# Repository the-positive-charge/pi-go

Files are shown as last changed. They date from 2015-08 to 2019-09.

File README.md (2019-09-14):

# pi-go
Pi-Go Kickstarter - Design Files

## IMPORTANT NOTICE 2019-09-14
**This design requires modification to add the 5V "safety" protection and the ID EEPROM as
specified by the Raspberry Pi Hat specification: https://github.com/raspberrypi/hats**

This directory contains the Cadsoft Eagle (v7.3) design files: Schematic, Layout and related files
The "Gerber Files" directory contains the fabrication files
The "Other Files" directory contains the BOM and other related files (design rules, netlist, etc.)

The Pi-Go design is released under the TAPR Open Hardware License:
https://www.tapr.org/ohl.html

The documentation for the Pi-Go design is released under the Creative Commons
Attribution-ShareAlike v4.0 license:
http://creativecommons.org/licenses/by-sa/4.0/

See the respective license files:
LICENSE-design.txt for full TAPR OHL text
LICENSE-documents.txt for full CC-BY-SA v4.0 text

2015 CC-BY-SA The Positive Charge, LLC

The Positive Charge, LLC has been disolved. Please give attribution to me directly (N8SQT)
2019 CC-BY-SA N8SQT / Bob Recny

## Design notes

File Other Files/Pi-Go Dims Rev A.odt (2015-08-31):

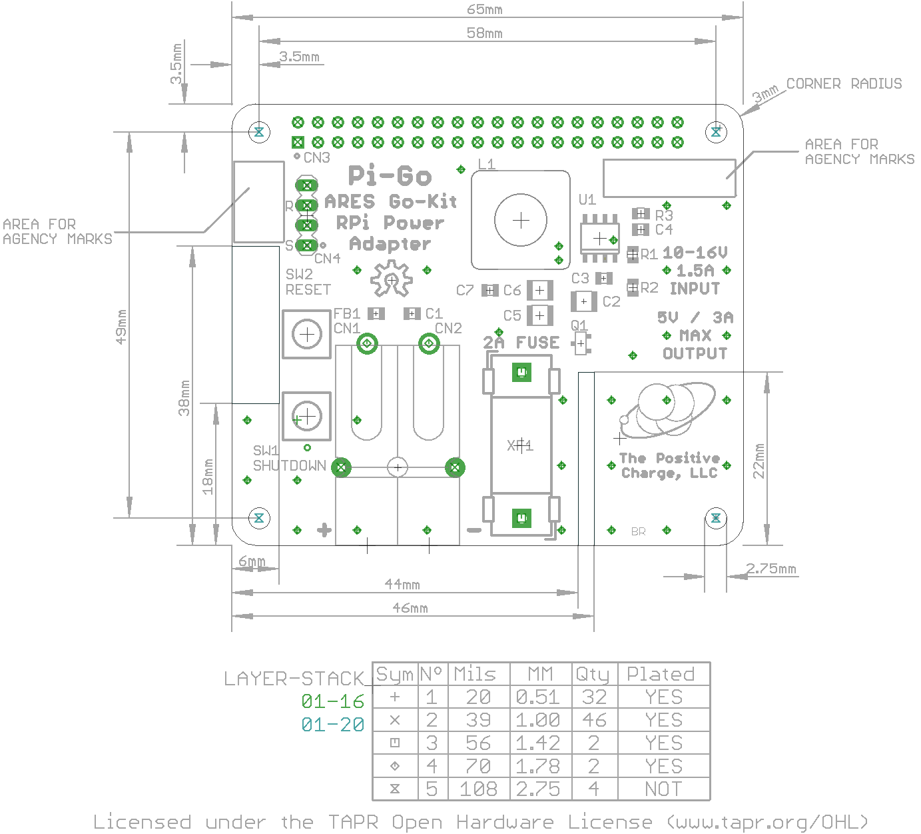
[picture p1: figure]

Board dimensions

- Dimensions in mm:
- Rounded corners = 3mm diameter, 4 places
- Milled slots
  - 20mm x 6mm on left edge
  - 2mm x 22mm on bottom edge

Notes:

- Board specifications for selected service level take precedence over these notes.
  - Material: FR-4
    - 1oz Copper External Layer
    - Thickness Tolerance ±0.0061”
  - Solder Mask: Standard Green, SMOBC
  - Vendor shall stamp agency marks on each board as required
  - Silkscreen Color = White, Component layer only
  - All holes size shall be located within 0.003” (0.08mm) diameter of true position from location shown on master pattern.
  - Finished hole size tolerance: ±003” (±0.08mm)
  - Front-to-Back layer registration to be within 0.003” (0.08mm)
  - Board outline shall conform to supplied Gerber data within 0.010” (0.25mm)
  - All internal corners 0.040” (1.01mm) of radius maximum

Board Stack-up – Use standard for service level, or:

All dimensions in inches unless otherwise noted:

Stack-up | Thickness | Tolerance (±) | Layer file ext. | Notes
Layer 1 | 0.0017 | 0.0004 | cmp | Top Layer
Laminate Core | 0.0580 | 0.0025
Layer 16 | 0.0017 | 0.0004 | sol | Bottom Layer
Overall | 0.0614 | 0.0061

The Positive Charge Pi-Go Rev A – 2015-08-11 Fabrication Details

Page 2 of 2 Hardware Design licensed under the TAPR Open Hardware License (www.tapr.org/OHL) (C) 2015 The Positive Charge, LLC, All text/Gerber and related documents licensed under the Creative Commons Attribution-ShareAlike 4.0 International License (http://creativecommons.org/licenses/by-sa/4.0/)

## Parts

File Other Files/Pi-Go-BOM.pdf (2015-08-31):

Pi-Go | Rev A | Page 1

Hardware Design licensed under the TAPR Open Hardware License (www.tapr.org/OHL)
(C) 2015 The Positive Charge, LLC, All text/Gerber and related documents licensed under the Creative Commons Attribution-ShareAlike 4.0 International License (http://creativecommons.org/licenses/by-sa/4.0/)
Qty Value | Parts | Description | MFG | MPN | DK-PN | NOTES | SMD | THD | Other (mech or DNI)
3 0.1uF | C1, C3, C7 | CAP CER 0.1UF 50V 10% X7R 0805 | Kemet | C0805C104K5RACTU | 399-1170-1-ND | 3
3 22uF | C2, C5, C6 | CAP CER 22UF 25V 10% X5R 1210 | Murata | GRM32ER61E226KE15L | 490-3889-1-ND | 3
1 1800pF | C4 | CAP CER 1800PF 50V 10% X7R 0805 | AVX Corporation | 08055C182KAT2A | 478-1374-1-ND | 1
2 1377G12 | CN1, CN2 | Anderson Powerpole 25A Pin Right Angle Bottom Low Force | Anderson Power | 1377G12 | 879-1377G12 (Mouser) | 2
1 SSW-120-01-T-D | CN3 | THROUGH-HOLE .025" SQ POST SOCKET | Sullins | SFH11-PBPC-D20-ST-BK | S9200-ND | Solder side mount | 1
1 DNI | CN4 | Pin Header – Holes Only, Do Not Install | N/A | N/A | N/A | Not Installed | | | 1
1 2A Fast Blow | F1 | FUSE GLASS 2A 250VAC 5X20MM | Bel Fuse Inc | 5MF 2-R | 507-1264-ND | Place in XF1 | | | 1
1 220R @ 100MHz, 3A | FB1 | FERRITE CHIP 220 OHM 3A 0805 | TDK Corporation | MPZ2012S221AT000 | 445-1568-1-ND | 1
1 10uH | L1 | FIXED IND 10UH 10A 16.5 MOHM SMD | Bourns | SRP1265A-100M | SRP1265A-100MCT-ND | 1
1 SI2343CDS | Q1 | MOSFET P-CH 30V 5.9A SOT-23 | Vishay Siliconix | SI2343CDS-T1-GE3 | SI2343CDS-T1-GE3CT-ND | 1
1 10K0 | R1 | RES SMD 10K OHM 1% 1/8W 0805 | Yageo | RC0805FR-0710KL | 311-10.0KCRCT-ND | 1
2 52K3 | R2, R3 | RES SMD 52.3K OHM 1% 1/8W 0805 | Yageo | RC0805FR-0752K3L | 311-52.3KCRCT-ND | 2
2 SWITCH-MOMENTARY-2SMD-4 | SW1, SW2 | SWITCH TACTILE SPST-NO 0.05A 24V | Apem | ADTSM61RVTR | 679-2381-1-ND | 2
1 AOZ1031A1 | U1 | IC REG BUCK ADJ 3A SYNC 8SOIC | Alpha & Omega | AOZ1031AI | 785-1253-1-ND | 1
1 1327 | XCN1 | Heavy Duty Power Connectors PP15/45 HOUSING ONLY RED | Anderson Power | 1327-BK | 879-1327-BK (Mouser) | Ass'y with CN1 | | | 1
1 1327BK | XCN2 | Heavy Duty Power Connectors PP15/45 HOUSING ONLY BLACK | Anderson Power | 1327G6-BK | 879-1327G6-BK (Mouser) | Ass'y with CN2 | | | 1
1 114555P2 | XCN3 | Anderson Powerpole Mounting Staple 2x1 | Anderson Power | 114555P2 | 879-114555P2 (Mouser) | 1
1 FUSE-5X20-HOLDER | XF1 | FUSE BLOK CARTRIDGE 300V 10A PCB | Littelfuse | 02540101Z | F1471-ND | 1
Parts Count | 16 | 5 | 4

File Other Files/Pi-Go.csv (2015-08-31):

Qty | Value | Device | Package | Parts | Description | MF | MPN | OC_FARNELL | OC_NEWARK | PROD_ID
3 | 0.1uF | C-EUC0805 | C0805 | C1, C3, C7 | CAPACITOR, European symbol
1 | 10K0 | R-US_R0805 | R0805 | R1 | RESISTOR, American symbol
1 | 10uH | SRP1265A | POWER-INDUCTOR-SHIELD | L1
1 | 114555P2 | 114555P2 | APP2X1CLIP | XCN3 | Anderson Powerpole Mounting Staple 2x1
2 | 1377G12 | 1377G12 | 1377G12 | CN1, CN2 | Anderson Powerpole 25A Pin Right Angle Bottom Low Force
1 | 1800pF | C-EUC0805 | C0805 | C4 | CAPACITOR, European symbol
3 | 22uF | C-EUC1210 | C1210 | C2, C5, C6 | CAPACITOR, European symbol
1 | 3A | FB0805 | C0805 | FB1 | Ferrite Bead
2 | 52K3 | R-US_R0805 | R0805 | R2, R3 | RESISTOR, American symbol
1 | AOZ1031A1 | AOZ1031A1 | AOZ1031AI-SO08 | U1 | EZBuck 3A Synchronous Buck Regulator
1 | DNI | MA04-1 | MA04-1 | CN4 | PIN HEADER |  |  | unknown | unknown
1 | FUSE-5X20-HOLDER | FUSE-5X20-HOLDER | LITTELFUSE-02540101Z | XF1 | 5x20mm Fuse Holder
1 | SI2343CDS | SI2343CDS | SOT23 | Q1 | Single P-Channel, MOSFET
1 | SSW-120-01-T-D | SSW-120-01-T-D | SSW-120-XX-X-D | CN3 | THROUGH-HOLE .025 SQ POST SOCKET"
2 | SWITCH-MOMENTARY-2SMD-4 | SWITCH-MOMENTARY-2SMD-4 | TACTILE_SWITCH_TALL | SW1, SW2 | Various NO switches- pushbuttons, reed, etc |  |  |  |  | SWCH-11966

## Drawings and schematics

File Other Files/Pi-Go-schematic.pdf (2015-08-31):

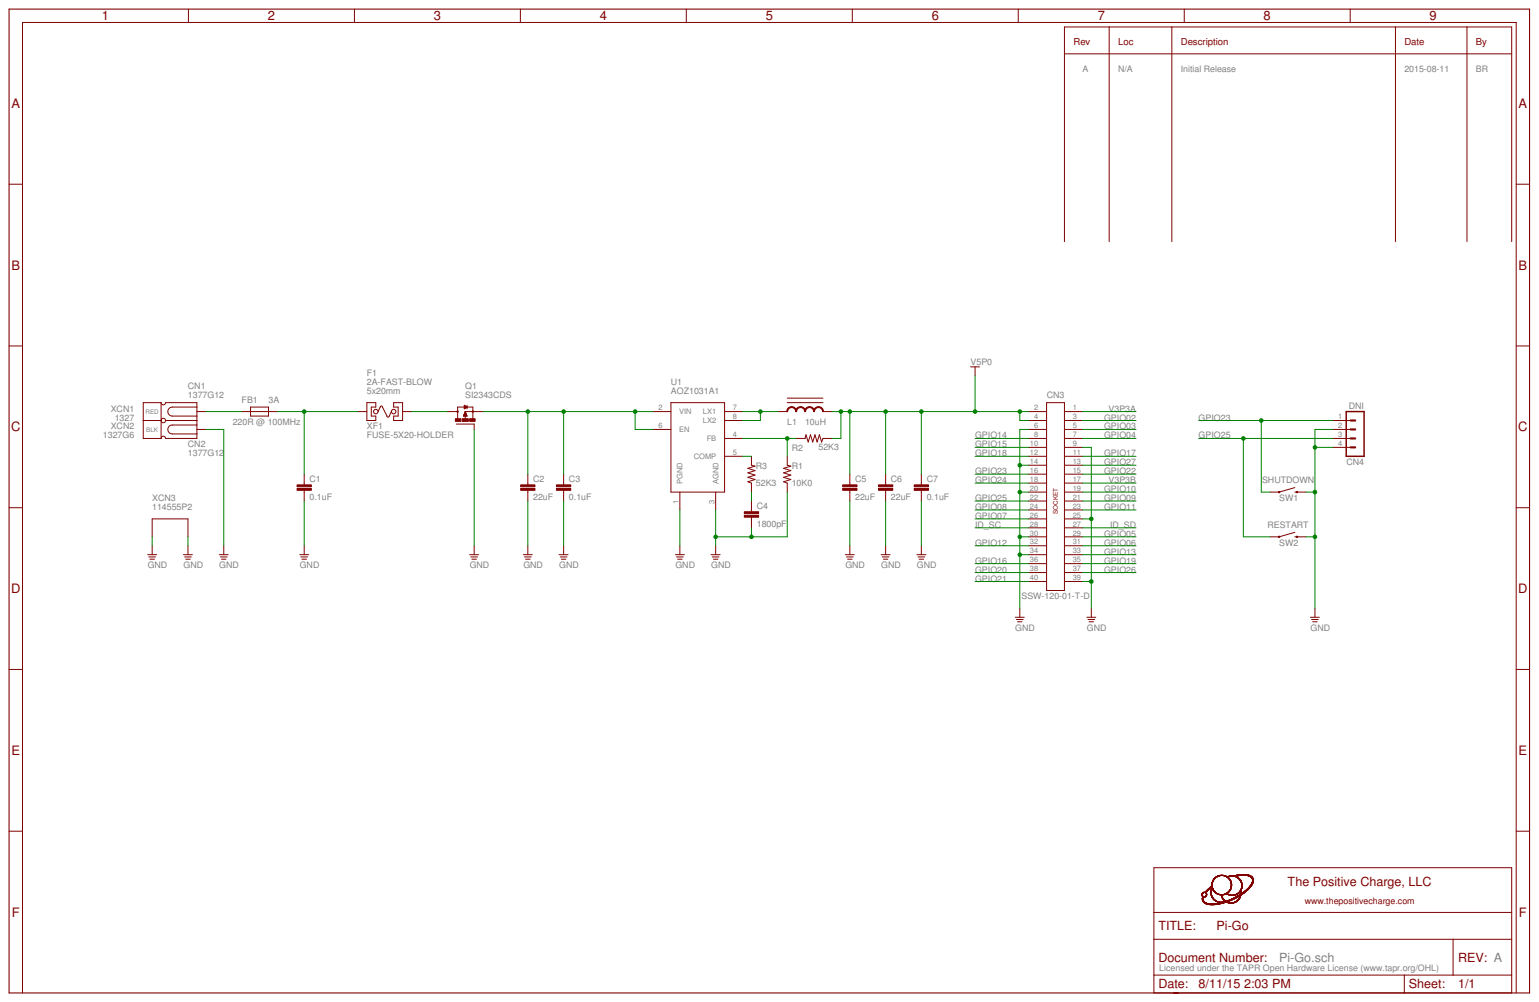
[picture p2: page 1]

Rev | Loc | Description | Date | By

The Positive Charge, LLC

Document Number: Pi-Go.sch Licensed under the TAPR Open Hardware License (www.tapr.org/OHL) | REV: A
Date: 8/11/15 2:03 PM | Sheet: 1/1

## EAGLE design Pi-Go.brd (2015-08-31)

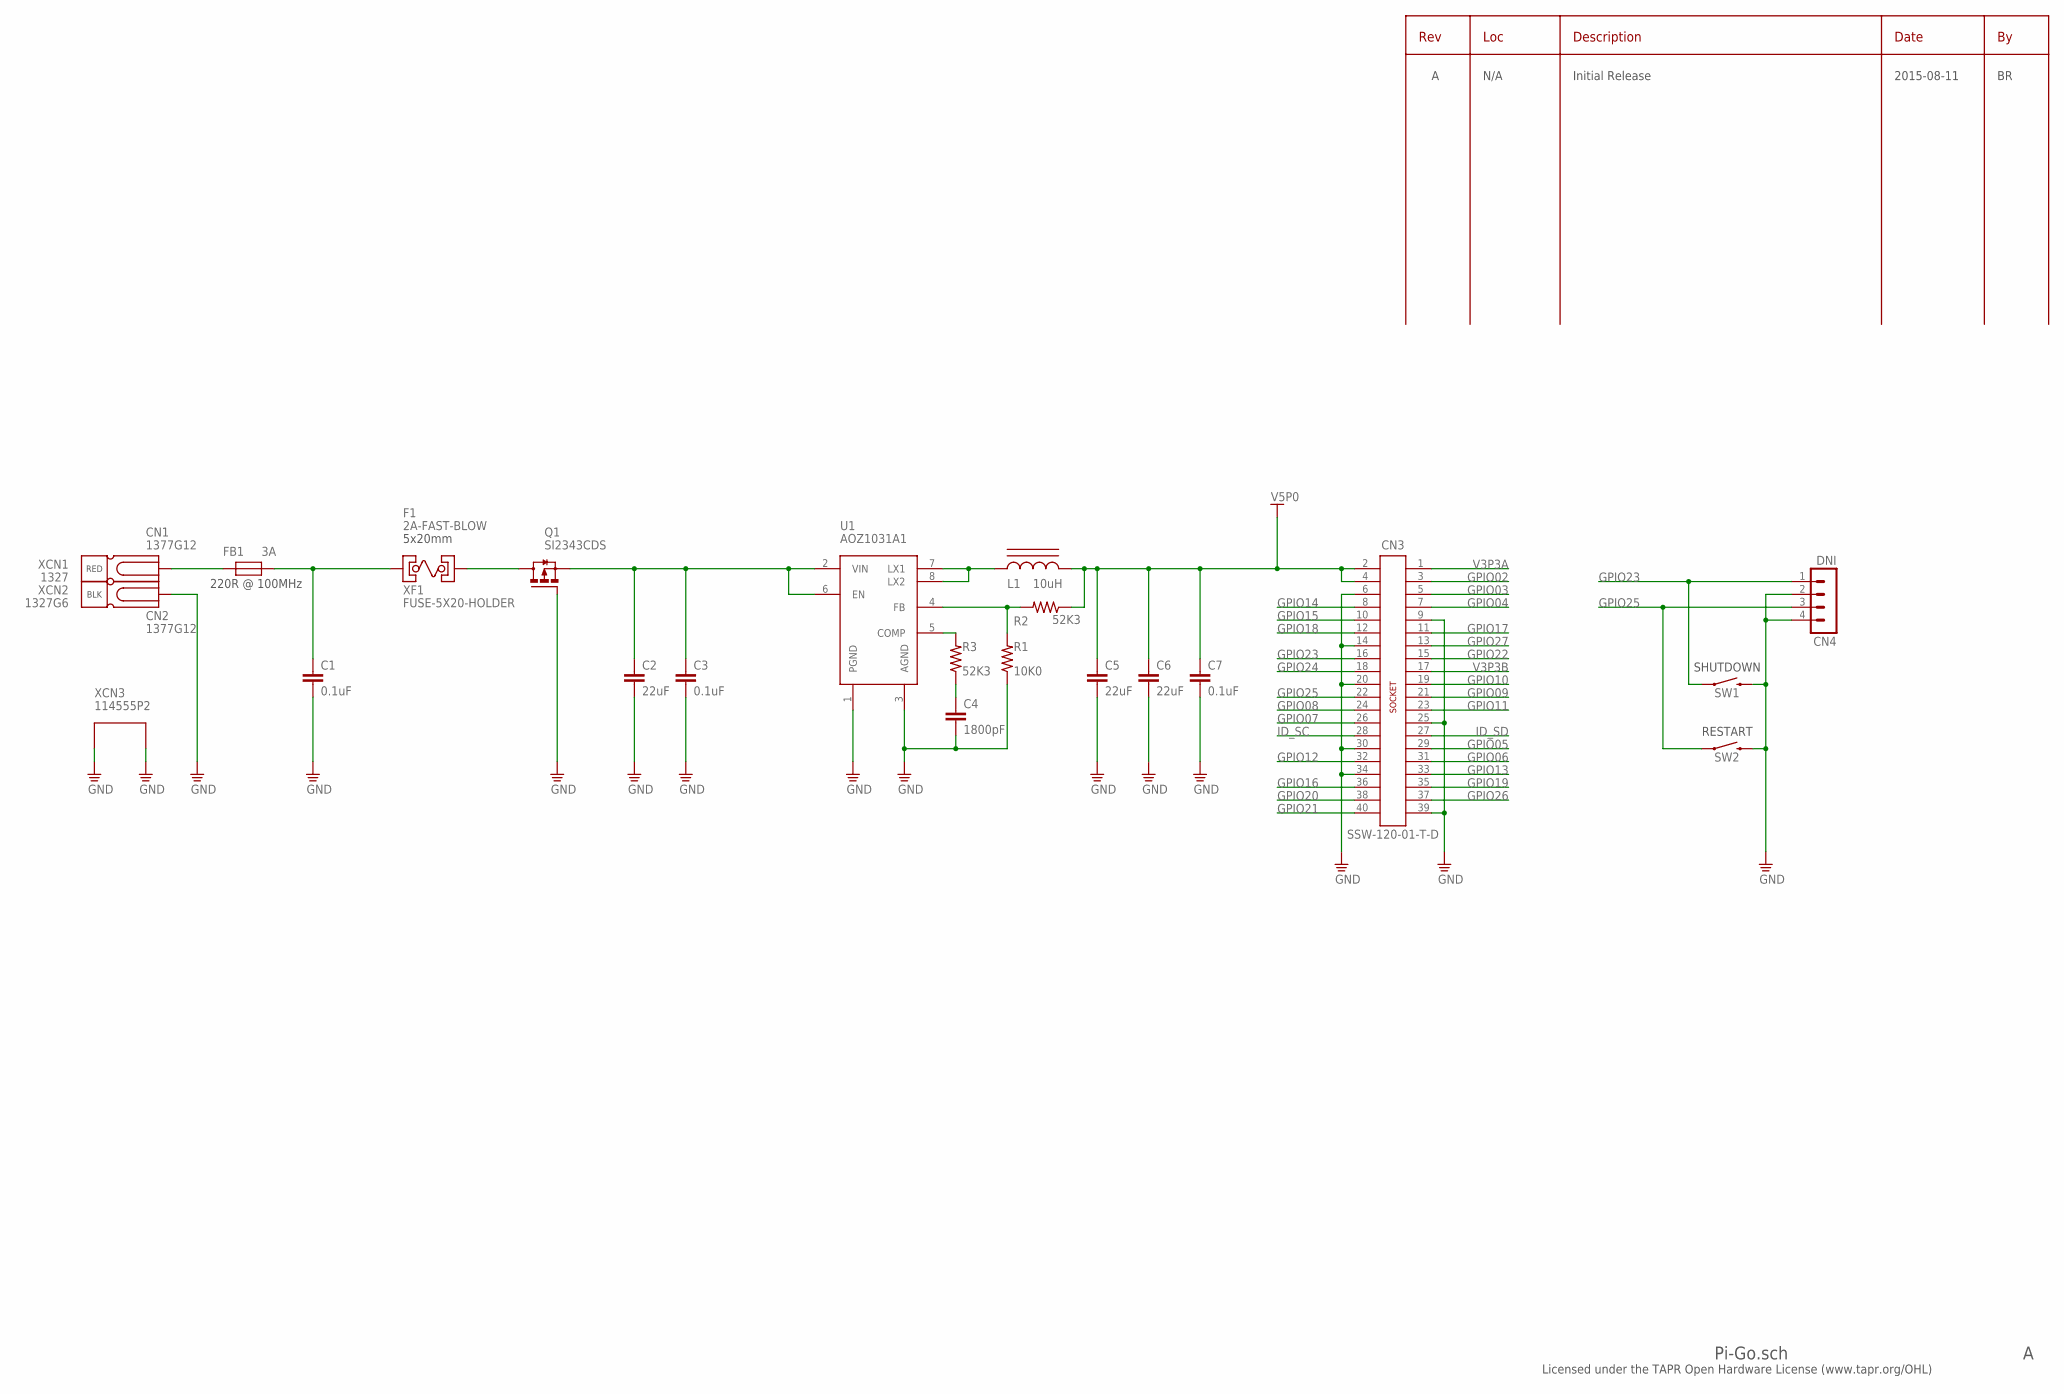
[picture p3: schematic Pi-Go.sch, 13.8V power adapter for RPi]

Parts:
C1, C3, C7: 0.1uF; C0805
C2, C5, C6: 22uF; C1210
C4: 1800pF; C0805
CN1, CN2: 1377G12
CN3: SSW-120-01-T-D; SSW-120-XX-X-D
CN4: DNI; MA04-1
FB1: 3A; C0805
L1: 10uH; POWER-INDUCTOR-SHIELD
Q1: SI2343CDS; SOT23
R1: 10K0; R0805
R2, R3: 52K3; R0805
SW1, SW2: SWITCH-MOMENTARY-2SMD-4; TACTILE_SWITCH_TALL
U1: AOZ1031A1; AOZ1031AI-SO08
XCN3: 114555P2; APP2X1CLIP
XF1: FUSE-5X20-HOLDER; LITTELFUSE-02540101Z

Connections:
COM2: C4.1, R3.1
COMP1: R3.2, U1.5 (COMP)
FB: R1.2, R2.2, U1.4 (FB)
FUSED: Q1.3 (D), XF1.2
GND: C1.2, C2.2, C3.2, C4.2, C5.2, C6.2, C7.2, CN2.P$1, CN3.6, CN3.9, CN3.14, CN3.20, CN3.25, CN3.30, CN3.34, CN3.39, CN4.2, CN4.4, Q1.1 (G), R1.1, SW1.B1 (2), SW1.B2 (2), SW2.B1 (2), SW2.B2 (2), U1.1 (PGND), U1.3 (AGND), XCN3.P$1 (1), XCN3.P$2 (2)
GPIO02: CN3.3
GPIO03: CN3.5
GPIO04: CN3.7
GPIO05: CN3.29
GPIO06: CN3.31
GPIO07: CN3.26
GPIO08: CN3.24
GPIO09: CN3.21
GPIO10: CN3.19
GPIO11: CN3.23
GPIO12: CN3.32
GPIO13: CN3.33
GPIO14: CN3.8
GPIO15: CN3.10
GPIO16: CN3.36
GPIO17: CN3.11
GPIO18: CN3.12
GPIO19: CN3.35
GPIO20: CN3.38
GPIO21: CN3.40
GPIO22: CN3.15
GPIO23: CN3.16, CN4.1, SW1.A1 (1), SW1.A2 (1)
GPIO24: CN3.18
GPIO25: CN3.22, CN4.3, SW2.A1 (1), SW2.A2 (1)
GPIO26: CN3.37
GPIO27: CN3.13
ID_SC: CN3.28
ID_SD: CN3.27
LX: L1.1, U1.7 (LX1), U1.8 (LX2)
unnamed: CN1.P$1, FB1.1
V3P3A: CN3.1
V3P3B: CN3.17
V5P0: C5.1, C6.1, C7.1, CN3.2, CN3.4, L1.2, R2.1
VIN: C2.1, C3.1, Q1.2 (S), U1.2 (VIN), U1.6 (EN)
VINFLT: C1.1, FB1.2, XF1.1

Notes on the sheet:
RED
BLK
220R @ 100MHz
SHUTDOWN
RESTART
5x20mm
N/A
Initial Release
2015-08-11
Pi-Go.sch
Licensed under the TAPR Open Hardware License (www.tapr.org/OHL)

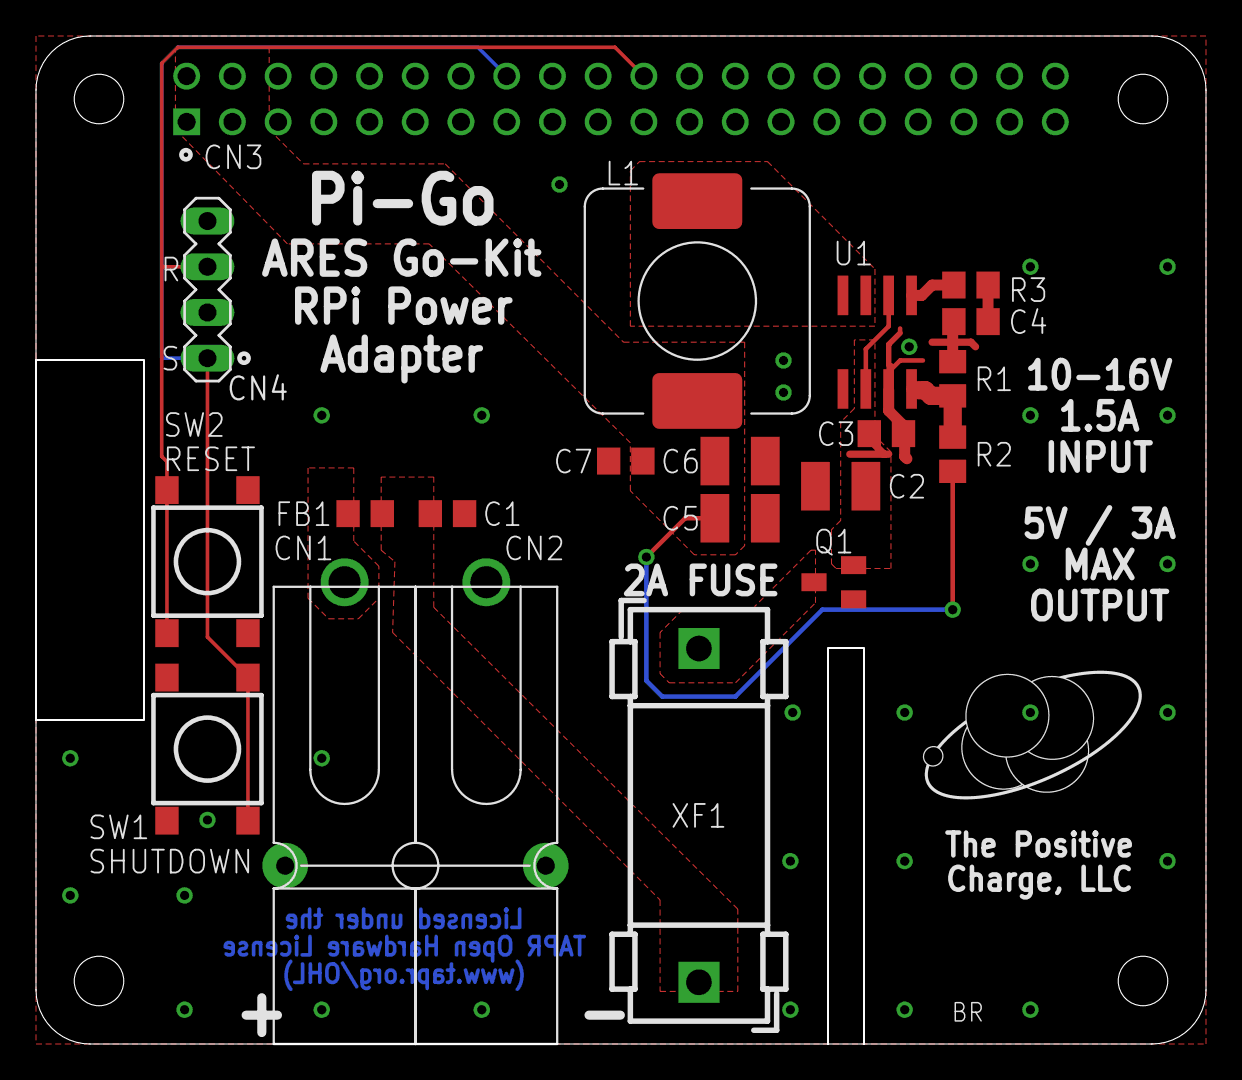
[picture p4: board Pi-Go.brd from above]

Board: 2 copper layers, 65.0 x 56.0 mm, 25 parts (1 on the bottom side), 12 nets.

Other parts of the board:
DRILEGEND: DRILEGEND
U$1: TPC-LOGO
U$3: OSHWLOGO_TOP_0.2

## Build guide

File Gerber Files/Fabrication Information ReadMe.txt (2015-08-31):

Pi-Go, Rev A

Gerber & Assembly files

Fabrication Drawing:
	Pi-Go Dims Rev A.pdf = Dimensioned Drawing
	
Milling:
	mil = milling
	hpgl = milling in HPGL format

Layers:
	cmp = copper layer 1 (component side)
	sol = copper layer 16 (solder side)

Silk Screen:
	plc = silk screen layer 1 (component side)
	pls = silk screen layer 16 (solder side) (not required)

Solder mask:
	stc = solder mask layer 1 (component side)
	sts = solder mask layer 16 (solder side)

Solder paste:
	crc = solder paste layer 1 (component side)
	crs = solder paste layer 16 (solder side) (no SMT on solder side)

Excellon drill:
	drd = drill file
	dri = drill information (text only)

Pick & Place files:
	mnt = pick & place layer 1 (component side)
	mnb = pick & place layer 16 (solder side)

Other files:
	netlist, drills, etc.
	drills

Hardware Design licensed under the 
TAPR Open Hardware License 
(www.tapr.org/OHL)

(C) 2015 The Positive Charge, LLC, All text/Gerber and related documents licensed under the 
Creative Commons Attribution-ShareAlike 4.0 International License
(http://creativecommons.org/licenses/by-sa/4.0/)

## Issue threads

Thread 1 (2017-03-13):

2x20 header

bob-was-here, 2017-03-13:
The header in the BOM is too wide and bumps into the mounting hardware.

A Sullins PPPC202LFBN-RC (Digi-Key S7123-ND) should be used.

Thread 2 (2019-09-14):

Modify design to include reverse voltage protection and ID EEPROM

n8sqt, 2019-09-14:
The original design did not include these items.

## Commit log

2015-08-31 Added design files
    [Pi-Go.brd, Pi-Go.sch]
2015-08-31 The rest of the files
    [DRILEGEND.CFG, Pi-Go-BOM.ods, Pi-Go-BOM.xlsx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]
2015-09-01 Corrected Excel BOM version (Anderson 1327 (Red) and 1327G6 (Black)
    [Pi-Go-BOM.xlsx]

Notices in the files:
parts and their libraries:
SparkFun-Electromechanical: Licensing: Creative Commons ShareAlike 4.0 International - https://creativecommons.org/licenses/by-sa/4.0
